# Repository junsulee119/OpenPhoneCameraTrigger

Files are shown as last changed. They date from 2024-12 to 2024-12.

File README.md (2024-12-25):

# OpenPhoneCameraTrigger

## Table of Contents
1. [Introduction](#introduction)
2. [Features](#features)
3. [How to Build Your Own OpenPhoneCameraTrigger](#how-to-build-your-own-openphonecameratrigger)
    1. [Required Components](#1-required-components)
    2. [Setting Up the Development Environment](#2-setting-up-the-development-environment-for-esp32)
    3. [Coding and Running](#3-coding-and-running)
    4. [Wiring and Connection Diagram](#4-wiring-and-connection-diagram)
    5. [3D Printing and Assembling the Enclosure](#5-3d-printing-and-assembling-the-enclosure)
4. [Version History](#code-version-history)
5. [Future improvement](#future-improvement)
6. [License](#license)

## Introduction
OpenPhoneCameraTrigger is a project designed to enable wireless control of camera trigger using an ESP32 based board. With this project, you can send volume control signals to trigger your phone camera's shutter remotely.

demoVideo (https://www.youtube.com/watch?v=Z1O2nStRBFU)
**Click the image to see Demo video!!**

---

## Features
- Wireless phone camera trigger via Bluetooth.
- Compact and portable design.
- Easy to customize and extend functionality.
- Open-source code and 3D-printable enclosure.

---

## How to Build Your Own OpenPhoneCameraTrigger

### 1. Required Components
Here is a list of components you'll need to build this project:
- **ESP32-C3 Super Mini**  – [Link](https://a.aliexpress.com/_oErgR53)
- **Push button** – [Link](https://a.aliexpress.com/_olNm9Id)
- **3.7V** 300mAh 602030 LiPo **Battery** – [Link](https://a.aliexpress.com/_omasVAl)
- TP4057 **Battery Charger Board** – [Link](https://a.aliexpress.com/_onq9YhJ)
- Dupont cable or jumper wire

Other
- USB type-C cable to connect esp32 with pc
- PC or Laptop etc.. for coding and debugging

To build enclosure
- 3D-printed enclosure (stl files in [stl](https://github.com/junsulee119/OpenPhoneCameraTrigger/tree/main/stl))
- M2.5 OD4mm 5mm long Threaded insert * 2 [Link](https://a.aliexpress.com/_oCb7Maz)
- M2.5 6mm long bolt [Link](https://a.aliexpress.com/_olOMYyt)

---

### 2. Setting Up the Development Environment for ESP32
Follow these steps to set up your development environment:
1. Install Arduino IDE (Tested on version 2.3.3)
2. Add the ESP32 board package to the IDE (Tested on version 3.1.0-RC3)
    1. Go to **Tools > Board > Boards Manager** or **Ctrl+Shift+B**
    2. Serch **'esp32'**
    3. Install **'esp32 by Espressif Systems'**
3. Connect ESP32 to PC and select proper COM port
    1. Connect ESP32 Super Mini board to PC using USB Type-C cable (make sure that the USB cable supports data transmission)
    2. Go to **Tools > Port** and **select proper COM port** that ESP32 is connected at
4. Select ESP32 SuperMini board
    1. Go to **Tools > Board > esp32**
    2. Select **'Nologo ESP32C3 Super Mini'** (Selecting 'ESP32C3 Dev Module wont work!)

---

### 3. Coding and Running
1. Clone this repository or download the project files.
2. Open the `OpenPhoneCameraTrigger.ino` file in your IDE.
3. Compile and upload the code.
4. Monitor the Serial Output to verify functionality.

---

### 4. Wiring and Connection Diagram

>[!TIP]
> Print the enclosure first and then measure the required length for each wire. Otherwise, the enclosure might not fit

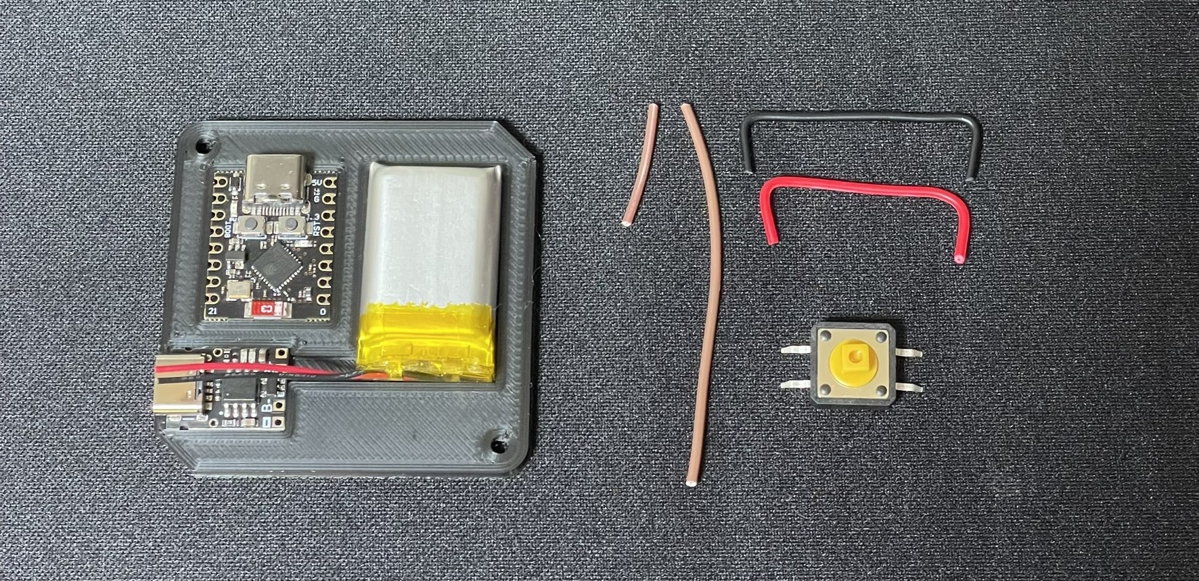
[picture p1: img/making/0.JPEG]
making0


Below is the connection diagram for the project:

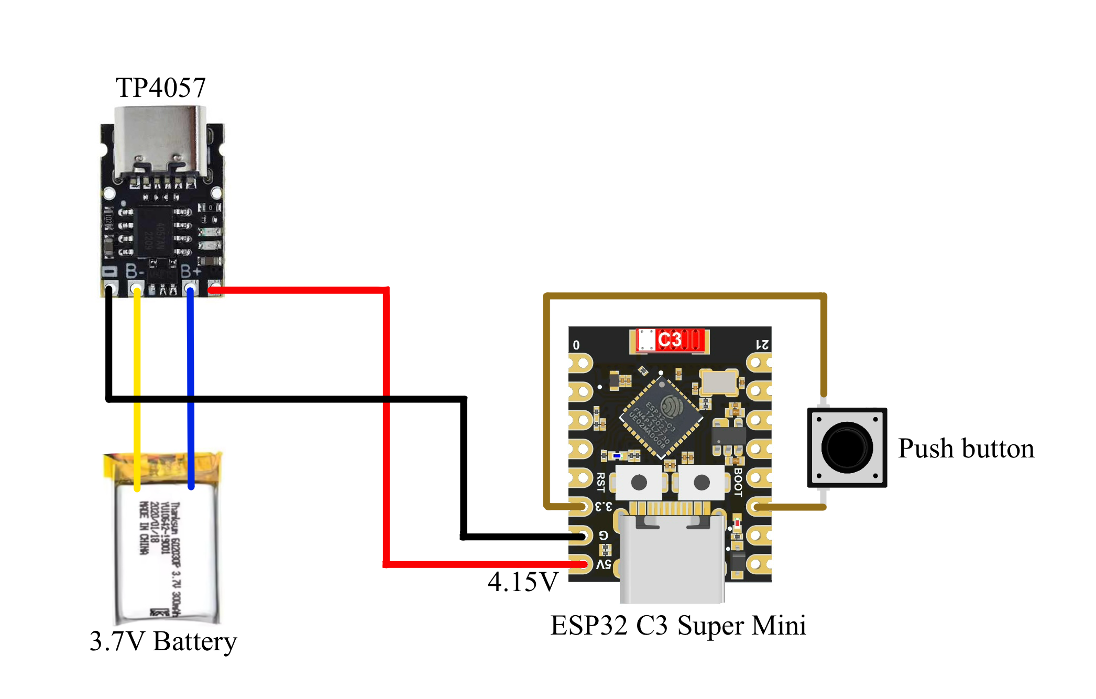
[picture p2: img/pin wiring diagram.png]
Pin wiring diagram


> [!CAUTION] 
> While handling batteries, always solder in a well-ventilated area, wear protective gear, and handle components with care to avoid burns or shorts. Use the correct temperature and soldering techniques, and never leave the iron unattended. When handling batteries, avoid short circuits, punctures, or heat exposure. Store and dispose of batteries properly, and always use the correct charger for safe operation

---

### 5. 3D Printing and Assembling the Enclosure
1. Print the provided `.stl` files using a 3D printer.
2. Gather additional assembly parts.
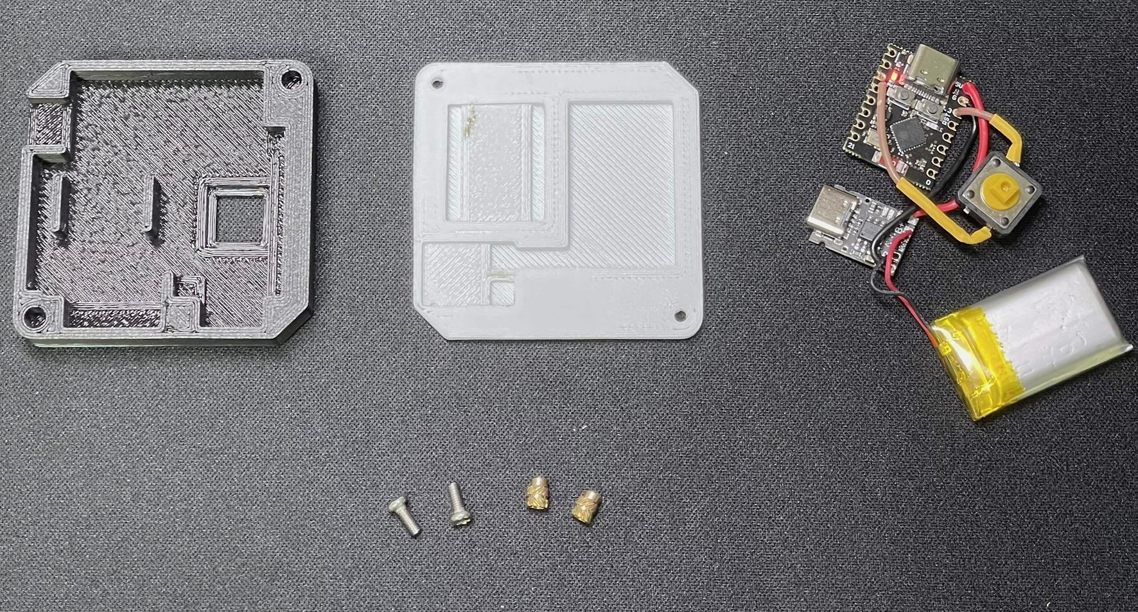
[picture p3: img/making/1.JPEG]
making1


3. Insert each PCB part into the corresponding position.
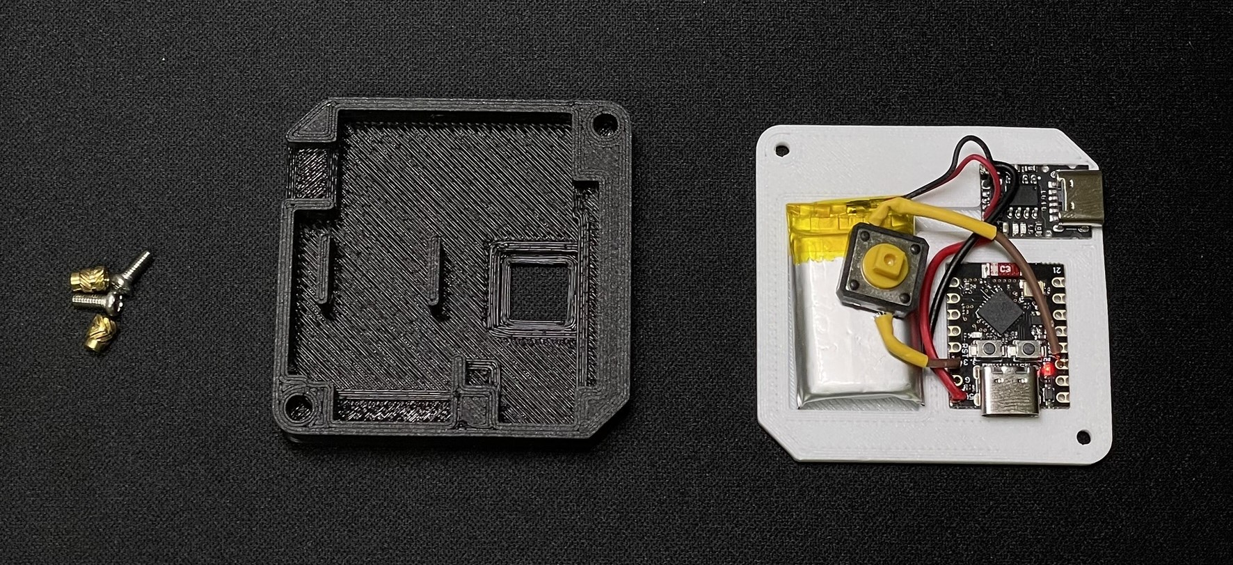
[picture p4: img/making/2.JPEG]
making2


4. Insert threaded inserts using soldering iron.
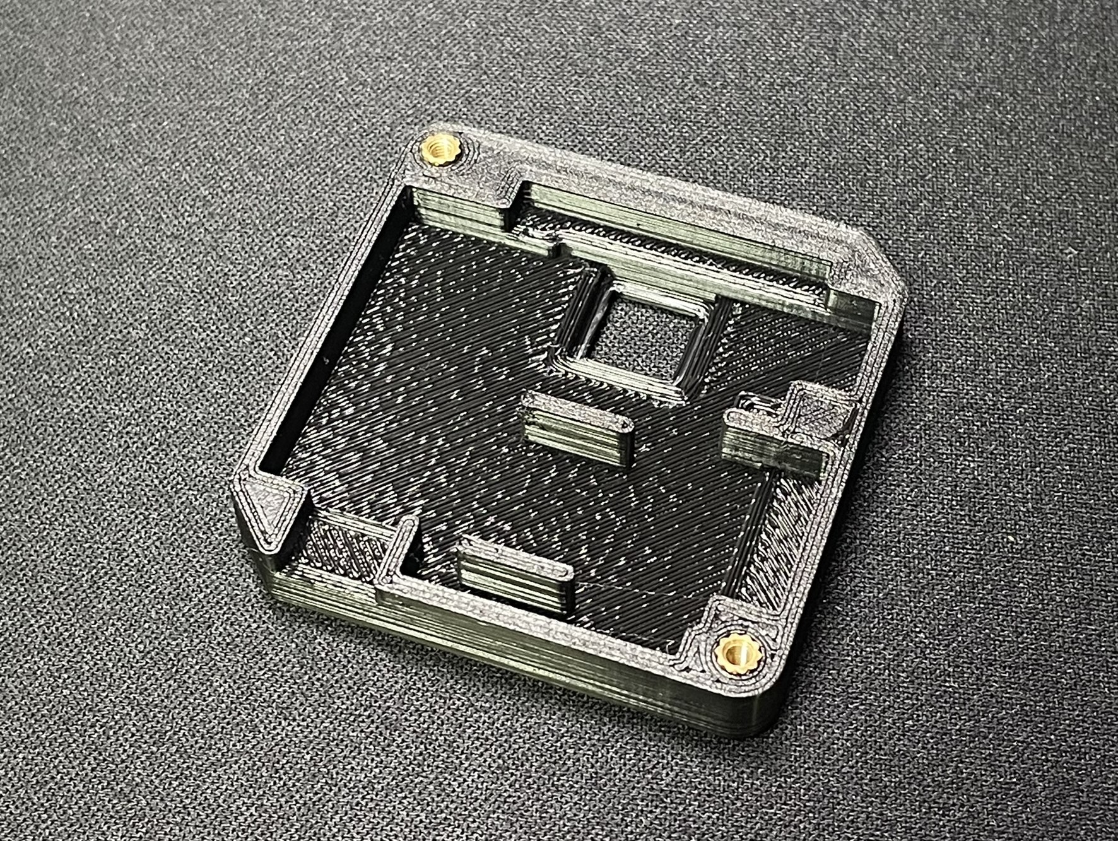
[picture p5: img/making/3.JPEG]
making3

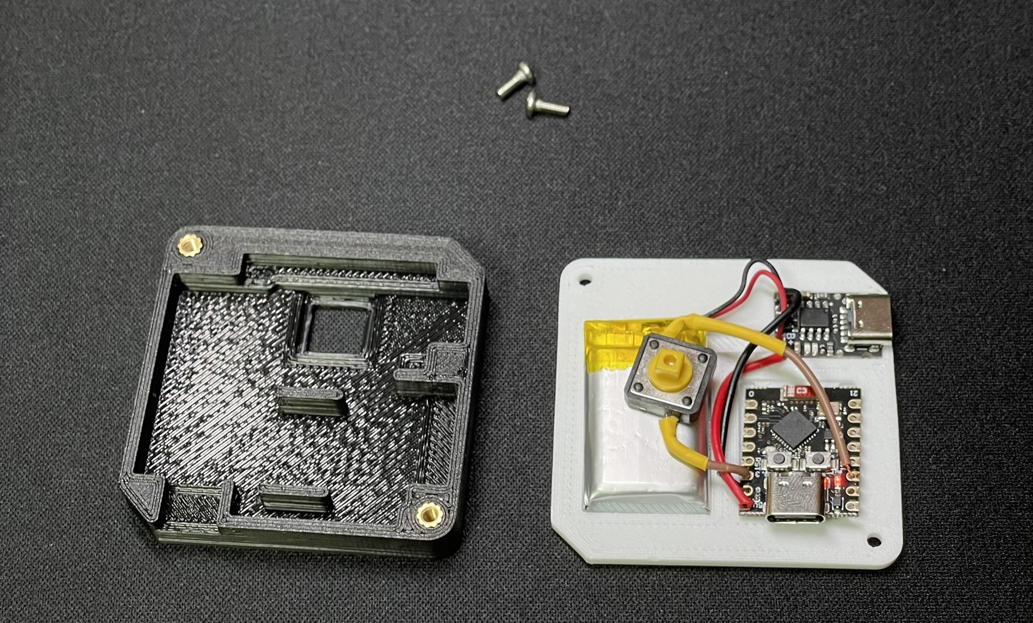
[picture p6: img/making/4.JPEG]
making4


5. Assemble top and bottom parts. Be careful not to get any wire stuck between two parts.
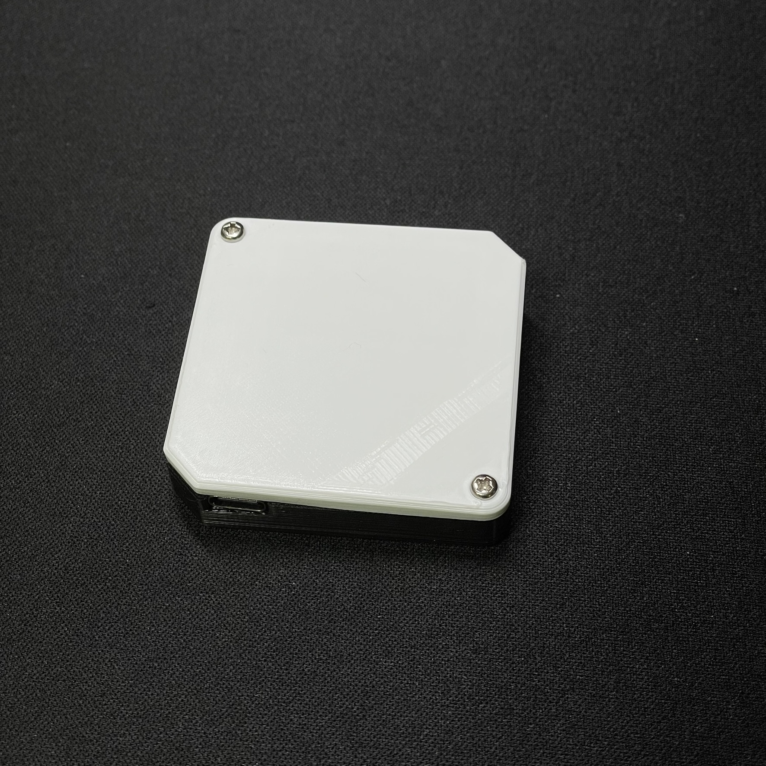
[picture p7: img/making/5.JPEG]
making5


6. Done!
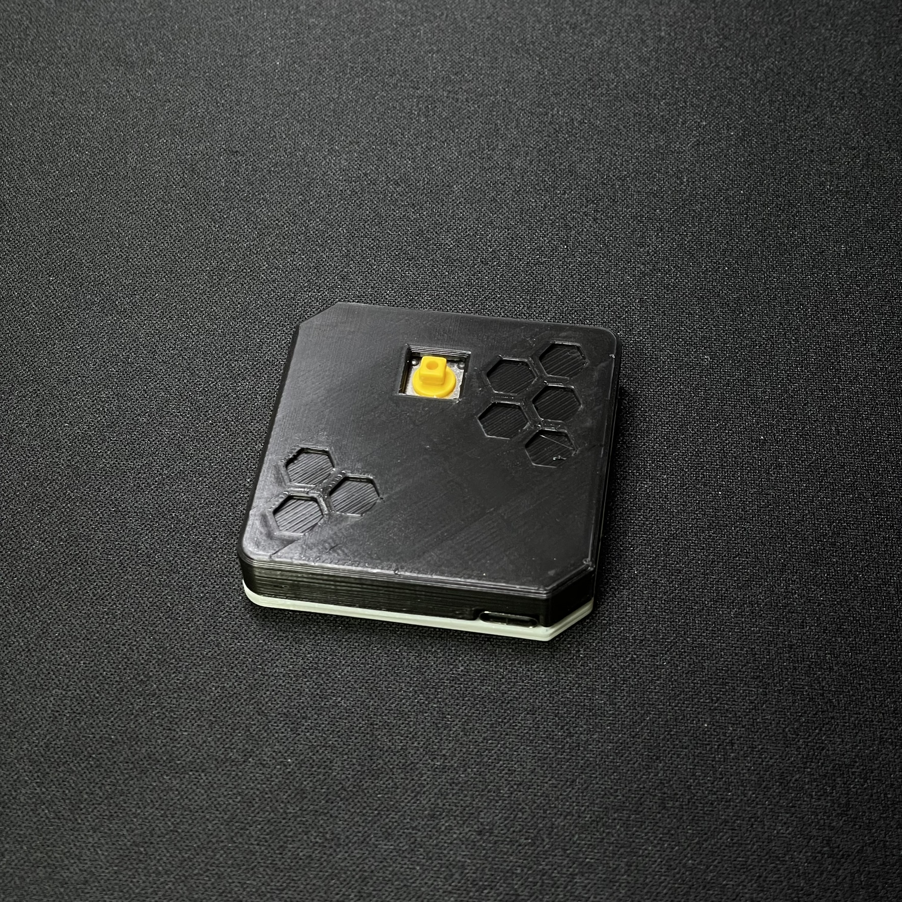
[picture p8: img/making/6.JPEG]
making6


---

## Code Version History
| Version | Release Date | Change Log |
|---|---|---|
| 1.0.0 | 2024-12-02 | Initial release. |

---

## 3D enclosure file Version History
| Version | Release Date | Change Log |
|---|---|---|
| 1.0.0 | 2024-12-02 | Initial release. |
| 1.0.1 | 2024-12-20 | Design improvement considering part step difference |

---

## Future improvement
- 일정 시간 이상 input 이 없을 경우 idle 상태(deep sleep mode) 전환으로 배터리 사용시간 개선 -> ESP32C3는 Deep-sleep mode 미지원 -> ESP32S3로 시도, Android폰에서 deep sleep이후 인식장애 발생(deep-sleep 으로 인한 BTLE연결정보 손실로 원인 추정) -> RTC메모리 사용하여 연결정보 보존
- 전원 인가시 무조건 BLE advertizing가 아닌 버튼이 꾹 눌리면 페어링모드 (advertizing mode)로 진입하는 것으로 개선 (BLE advertizing은 배터리 소모 높음 → 배터리시간 개선, 전원 인가시 무조건 advertizing mode로 진입하는 것이 아닌 사용자 조작을 통해 사용자의 통제 범위 증가)
- 더 비싼 배터리 충전 / 방전 보드로 idle 상태에서 발생하는 battery drain 양 최소화 혹은 배터리와 배터리 충전 / 방전 보드 사이에 스위치 추가하여 수동으로 키고 끌 수 있게 개선
- 버튼이 눌린 시간 측정하여 버튼 꾹 누르면 영상촬영(각 휴대폰의 음량버튼 꾹 누름 설정) 기능 추가
- 적절한 저항과 납땜장비가 없어 충전보드의 충전전류가 배터리 용량에 비해 과도하게 높은 점 개선
- 충전 LED 정보 외부로 나타나게 개선

## License
The code for this project is licensed under the **GNU AGPL v3.0**. 

The 3D enclosure files are licensed under **CC BY-NC-SA 4.0**.

For more details, see the `LICENSE` file under each directory or visit [GNU AGPL v3.0 License](https://www.gnu.org/licenses/agpl-3.0.html), [CC BY-NC-SA 4.0](https://creativecommons.org/licenses/by-nc-sa/4.0/).

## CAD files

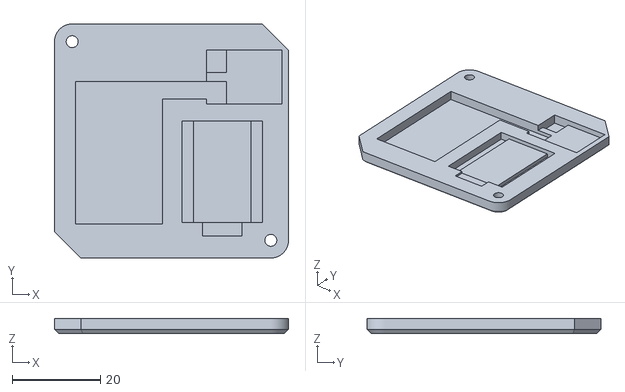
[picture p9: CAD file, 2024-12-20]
stl/top.stl
53.0 x 53.0 x 3.50

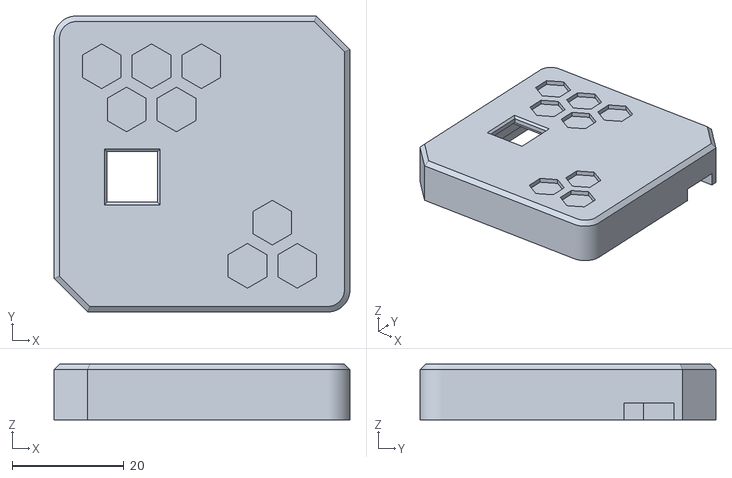
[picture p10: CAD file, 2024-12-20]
stl/bottom.stl
53.0 x 53.0 x 10.0

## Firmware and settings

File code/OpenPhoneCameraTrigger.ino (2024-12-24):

//SPDX-FileCopyrightText: © 2024 Junsu Lee <junsulee119@gmail.com>
//SPDX-License-Identifier: GNU Affero General Public License v3.0
//Version 1.0.0

#include <BLEDevice.h>
#include <BLEServer.h>
#include <BLEHIDDevice.h>
#include <HIDTypes.h>
#include <HIDKeyboardTypes.h>

#define HID_CONSUMER_CONTROL 0x030C

#define BUTTON_PIN 7 // GPIO pin connected to the button

// Global variables for BLE HID
BLEHIDDevice* hid;
BLECharacteristic* input;
BLEServer* server;
BLEAdvertising* advertising;

// HID Report Descriptor for Consumer Control (Volume Up)
uint8_t reportMap[] = {
    0x05, 0x0C,       // Usage Page (Consumer Page)
    0x09, 0x01,       // Usage (Consumer Controls)
    0xA1, 0x01,       // Collection (Application)
    0x85, 0x01,       // Report ID (1)
    0x15, 0x00,       // Logical Minimum (0)
    0x25, 0x01,       // Logical Maximum (1)
    0x75, 0x01,       // Report Size (1)
    0x95, 0x02,       // Report Count (2) - Need 2 bits for Up and Down
    0x09, 0xE9,       // Usage (Volume Up)
    0x09, 0xEA,       // Usage (Volume Down)
    0x81, 0x02,       // Input (Data, Variable, Absolute)
    0x95, 0x06,       // Report Count (6) - Padding bits
    0x75, 0x01,       // Report Size (1)
    0x81, 0x03,       // Input (Constant)
    0xC0              // End Collection
};

// Button flag for button shifting (VolUp <-> VolDown)
int btnFlag = 1; // 1 -> VolUp, -1 -> VolDown

// Callback class for connection events
class MyServerCallbacks : public BLEServerCallbacks {
    void onConnect(BLEServer* pServer) {
        Serial.println("Device connected");
    }

    void onDisconnect(BLEServer* pServer) {
        Serial.println("Device disconnected");
        advertising->start(); // Restart advertising
    }
};

// Functions to send a Consumer Control key press
void sendVolumeUp() {
    Serial.println("Sending Volume Up...");
    uint8_t report[] = {0b00000001}; // Bit 0 for Volume Up
    
    // Check if input characteristic exists and a device is connected
    if (input && server->getConnectedCount() > 0) {
        input->setValue(report, sizeof(report));
        input->notify();
        Serial.println("Key press sent!");
    } else {
        Serial.println("Cannot send key press - no connection");
    }
}

void sendVolumeDown() {
    Serial.println("Sending Volume Down...");
    uint8_t report[] = {0b00000010}; // Bit 1 for Volume Down
    
    // Check if input characteristic exists and a device is connected
    if (input && server->getConnectedCount() > 0) {
        input->setValue(report, sizeof(report));
        input->notify();
        Serial.println("Key press sent!");
    } else {
        Serial.println("Cannot send key press - no connection");
    }
}

// Function to send key release event
void sendKeyRelease() {
    Serial.println("Sending key release...");
    
    // Empty key report indicates no keys are pressed
    uint8_t emptyReport[] = {0b00000000};
    
    // Check if input characteristic exists and a device is connected
    if (input && server->getConnectedCount() > 0) {
        input->setValue(emptyReport, sizeof(emptyReport));  // Set empty report
        input->notify();  // Send notification
        Serial.println("Key release sent!");
    } else {
        Serial.println("Cannot send key release - no connection");
    }
}

// Initial setup function - runs once when device starts
void setup() {
    // Initialize serial communication for debugging
    Serial.begin(115200);  // Set high baud rate for fast communication
    while (!Serial) { delay(10); } // Wait for Serial to be ready
    
    Serial.println("==== ESP32 BLE Volume Control ====");

// ButtonPress setup
    // Configure the button pin as input with an internal pull-down resistor
    pinMode(BUTTON_PIN, INPUT_PULLDOWN);

// BLE setup
    // Initialize BLE
    BLEDevice::init("OpenCameraTrigger");  // Set device name
    server = BLEDevice::createServer();  // Create BLE server and set connection callbacks
    server->setCallbacks(new MyServerCallbacks());

    // Security Settings
    BLESecurity* security = new BLESecurity();
    security->setAuthenticationMode(ESP_LE_AUTH_BOND);
    security->setCapability(ESP_IO_CAP_NONE);
    security->setInitEncryptionKey(ESP_BLE_ENC_KEY_MASK | ESP_BLE_ID_KEY_MASK);

    // Initialize BLE HID
    hid = new BLEHIDDevice(server);
    input = hid->inputReport(1); // Report ID 1
    input->setAccessPermissions(ESP_GATT_PERM_READ_ENCRYPTED | ESP_GATT_PERM_WRITE_ENCRYPTED);
    hid->reportMap((uint8_t*)reportMap, sizeof(reportMap));
    hid->manufacturer()->setValue("ESP32 BLE Volume Control");
    hid->pnp(0x02, 0x1234, 0x5678, 0x0100);
    hid->hidInfo(0x00, 0x01);

    // Start HID services
    hid->startServices();

    // Configure advertising
    advertising = BLEDevice::getAdvertising();
    advertising->setAppearance(HID_CONSUMER_CONTROL);
    advertising->addServiceUUID(hid->hidService()->getUUID());
    advertising->start();

    Serial.println("==== BLE Volume Control Ready ====");
}

void loop() {
    // Read the state of the button
    int buttonState = digitalRead(BUTTON_PIN);

    if (server->getConnectedCount() > 0) {
        //Serial.println("Connected - Redy to send keys...");
       
        // Check if the button is pressed (HIGH because of the pull-down resistor)
        if (buttonState == HIGH) {
          Serial.println("Button press detected, sending signal...");
          if (btnFlag > 0) { // If btnFlag == 1
            sendVolumeUp(); // Send VolUp
            delay(100); // Short delay to simulate key press
            sendKeyRelease();
            Serial.println("Volume Up sent!");
            btnFlag *= -1; // Shift btnFlag to -1
          } 
          else if (btnFlag < 0) { // If btnFlag == -1
            sendVolumeDown(); // Send VolDown
            delay(100); // Short delay to simulate key press
            sendKeyRelease();
            Serial.println("Volume Down sent!");
            btnFlag *= -1; // Shift btnFlag to 1
          }
          delay(300); // Short delay to prevent fast shifting
        }
    } else {
        // If no device is connected, wait and continue checking
        Serial.println("Waiting for connection...");
        delay(1000);      // No device connected, wait and retry
    }
}

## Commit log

2024-12-02 Created code file
    Created code file to upload Arduino code
2024-12-11 massive updates!!!
    [bottom.stl, top.stl]
2024-12-20 new stl file update!
    [bottom.stl, top.stl]
